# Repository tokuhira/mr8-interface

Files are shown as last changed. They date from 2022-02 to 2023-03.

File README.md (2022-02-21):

# mr8-interface

KO PROPO製のプロポセットMC-8/MR-8にマルチプレクサ機能等を追加するプロジェクトです。

# Features

CMOSロジックICのマルチプレクサを利用してプロポからの操作と別系統からの操作を選択できます。
操作系統の切り替えはMC-8の操作スティック押下で行います。
CH-Eを押すと別系統の操作が有効になり、CH-Fを押すとプロポによる手動操作に戻ります。
別系統との電気信号は絶縁されているため、異なる電源系統のユニットとも接続できます。
おまけ機能で両系統のステアリングともにリバース信号も出力します。
おまけ機能でプロポ操作に対応するS.BUS信号も出力する予定ですが、プログラムは未実装です。

# Requirement

Adafruit QT Pyが別途必要です。

# Installation

このボードとAdafruit QT Pyは直接ハンダ付けします。
このボードとMR-8の接続については回路図を参照のうえ、ハーネスもしくは添付のミニ基板を使用してください。
このボードとRCシステム（スロットルに対応するESC、ならびにステアリングに対応するサーボ）の接続についても回路図を参照してください。
TAKACHI製のプラスチックケースTW4-2-5に格納することができます。
TAKACHI製のプラスチックケースSW-40にも格納することができますが、その場合はマウントホールのはみ出し部を切り落とす必要があります。

# Usage

各々方でご自由に応用していただけます。

# Note

可用性、安全性、その他いかなる性質も保証しません。
いかなる用法も、またのその結果も保証しません。

# Author

* @tokuhira (twitter)
* github.com/tokuhira

# License

BSD 3-Clause License

Copyright (c) 2020, tokuhira.net
All rights reserved.

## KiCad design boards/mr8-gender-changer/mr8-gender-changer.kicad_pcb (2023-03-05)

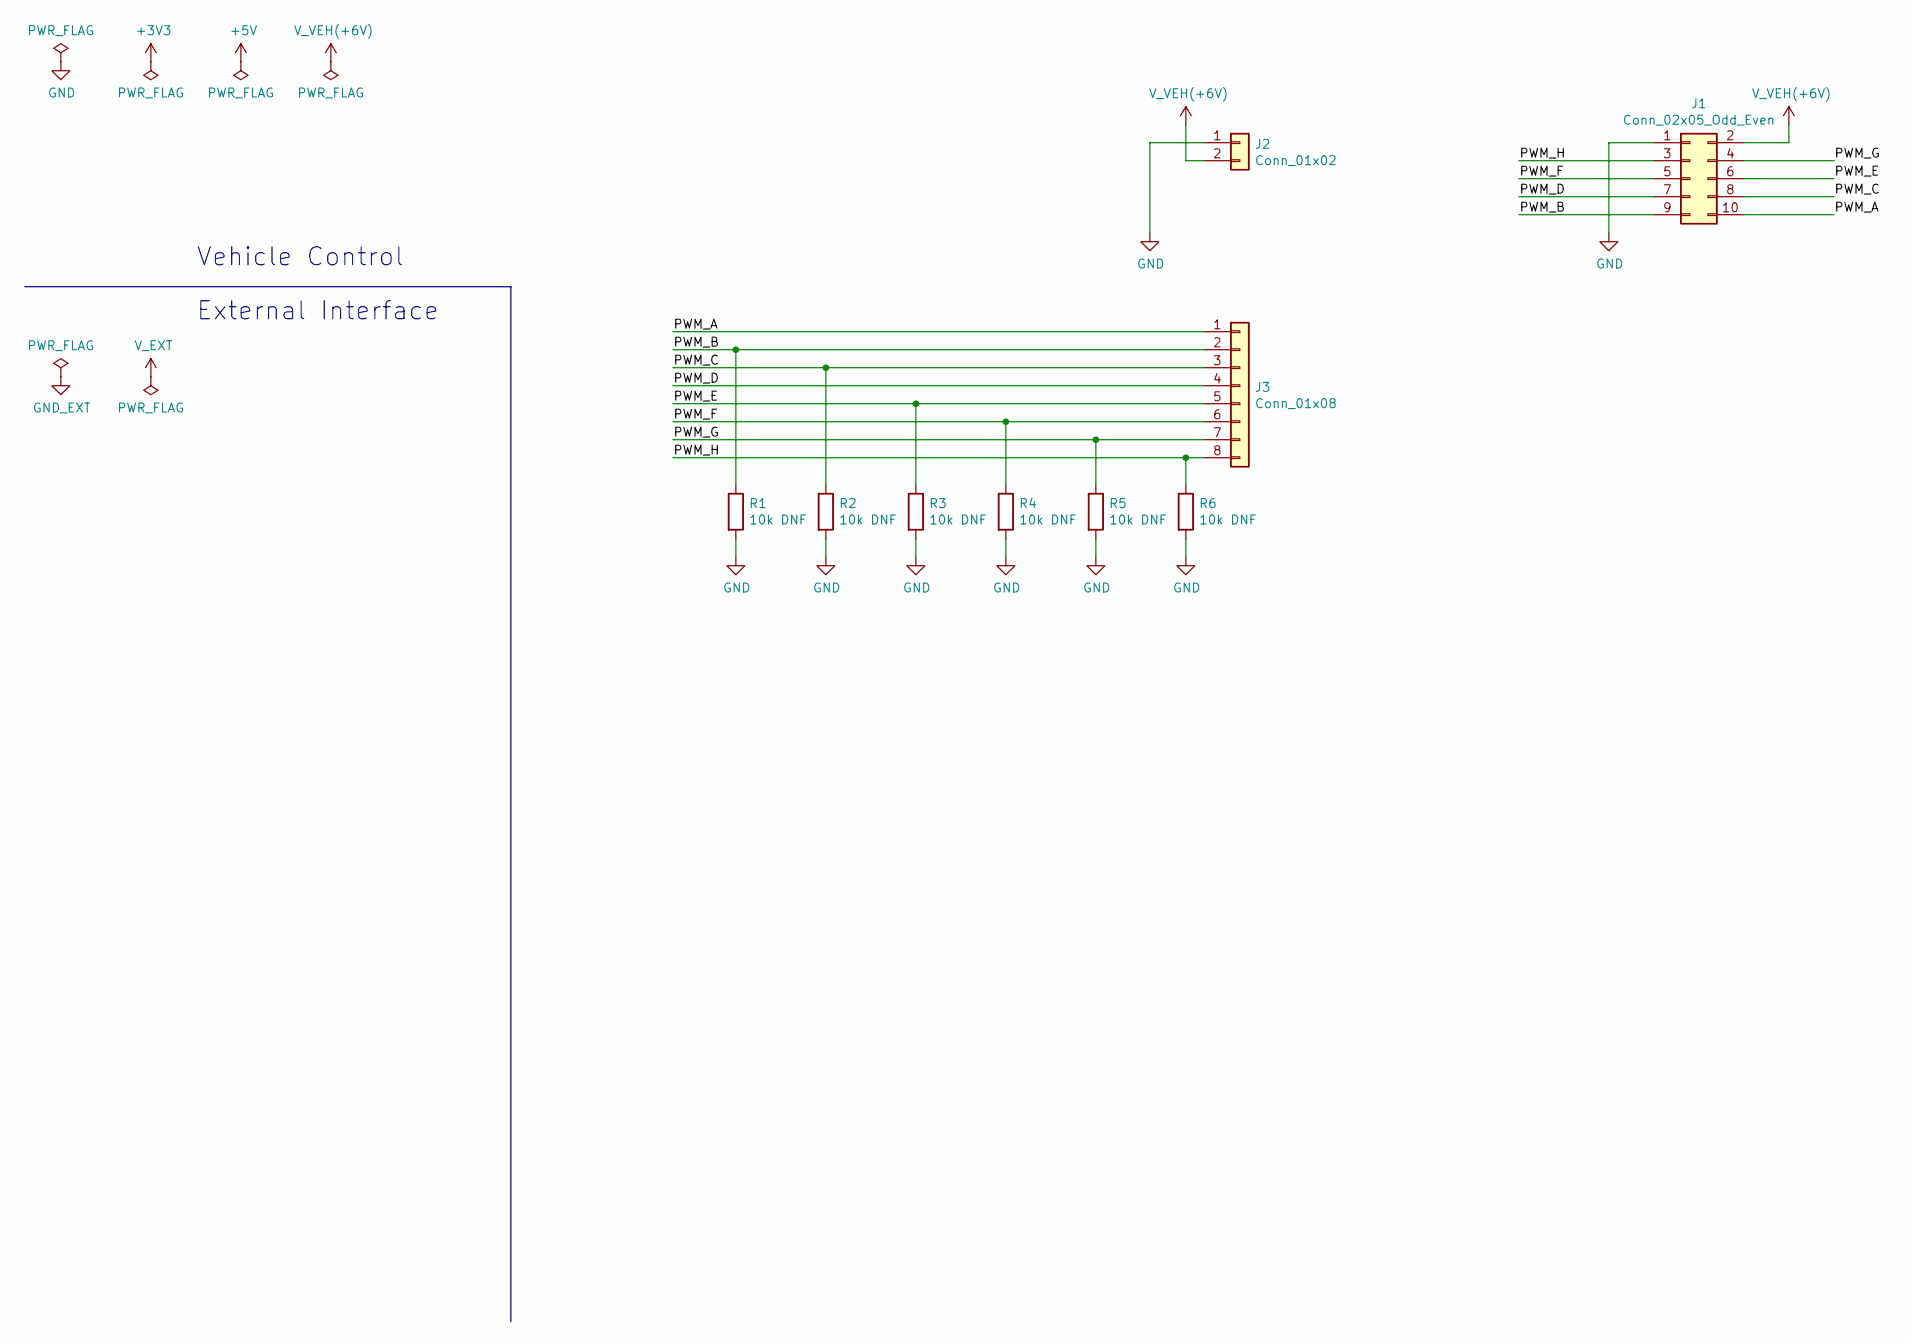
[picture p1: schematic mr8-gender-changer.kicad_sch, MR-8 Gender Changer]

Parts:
J1: Conn_02x05_Odd_Even; PinSocket_1x10_P2.54mm_Vertical
J2: Conn_01x02; PinSocket_1x02_P2.54mm_Vertical
J3: Conn_01x08; PinSocket_1x08_P2.54mm_Vertical
R1, R2, R3, R4, R5, R6: 10k DNF; R_0603_1608Metric_Pad0.98x0.95mm_HandSolder

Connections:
+V_VEH: J1.2, J2.2
/PWM_A: J1.10, J3.1
/PWM_B: J1.9, J3.2, R1.1
/PWM_C: J1.8, J3.3, R2.1
/PWM_D: J1.7, J3.4
/PWM_E: J1.6, J3.5, R3.1
/PWM_F: J1.5, J3.6, R4.1
/PWM_G: J1.4, J3.7, R5.1
/PWM_H: J1.3, J3.8, R6.1
GND: J1.1, J2.1, R1.2, R2.2, R3.2, R4.2, R5.2, R6.2

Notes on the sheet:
Vehicle Control
External Interface

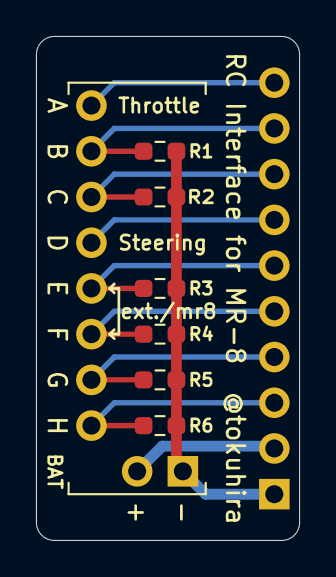
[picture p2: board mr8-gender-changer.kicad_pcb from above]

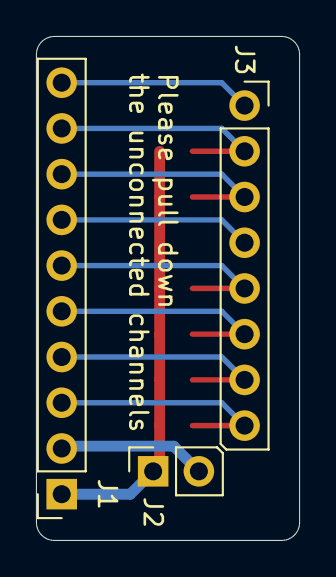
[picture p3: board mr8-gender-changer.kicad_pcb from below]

Board: 2 copper layers, 14.6 x 28.0 mm, 9 parts (3 on the bottom side), 10 nets.

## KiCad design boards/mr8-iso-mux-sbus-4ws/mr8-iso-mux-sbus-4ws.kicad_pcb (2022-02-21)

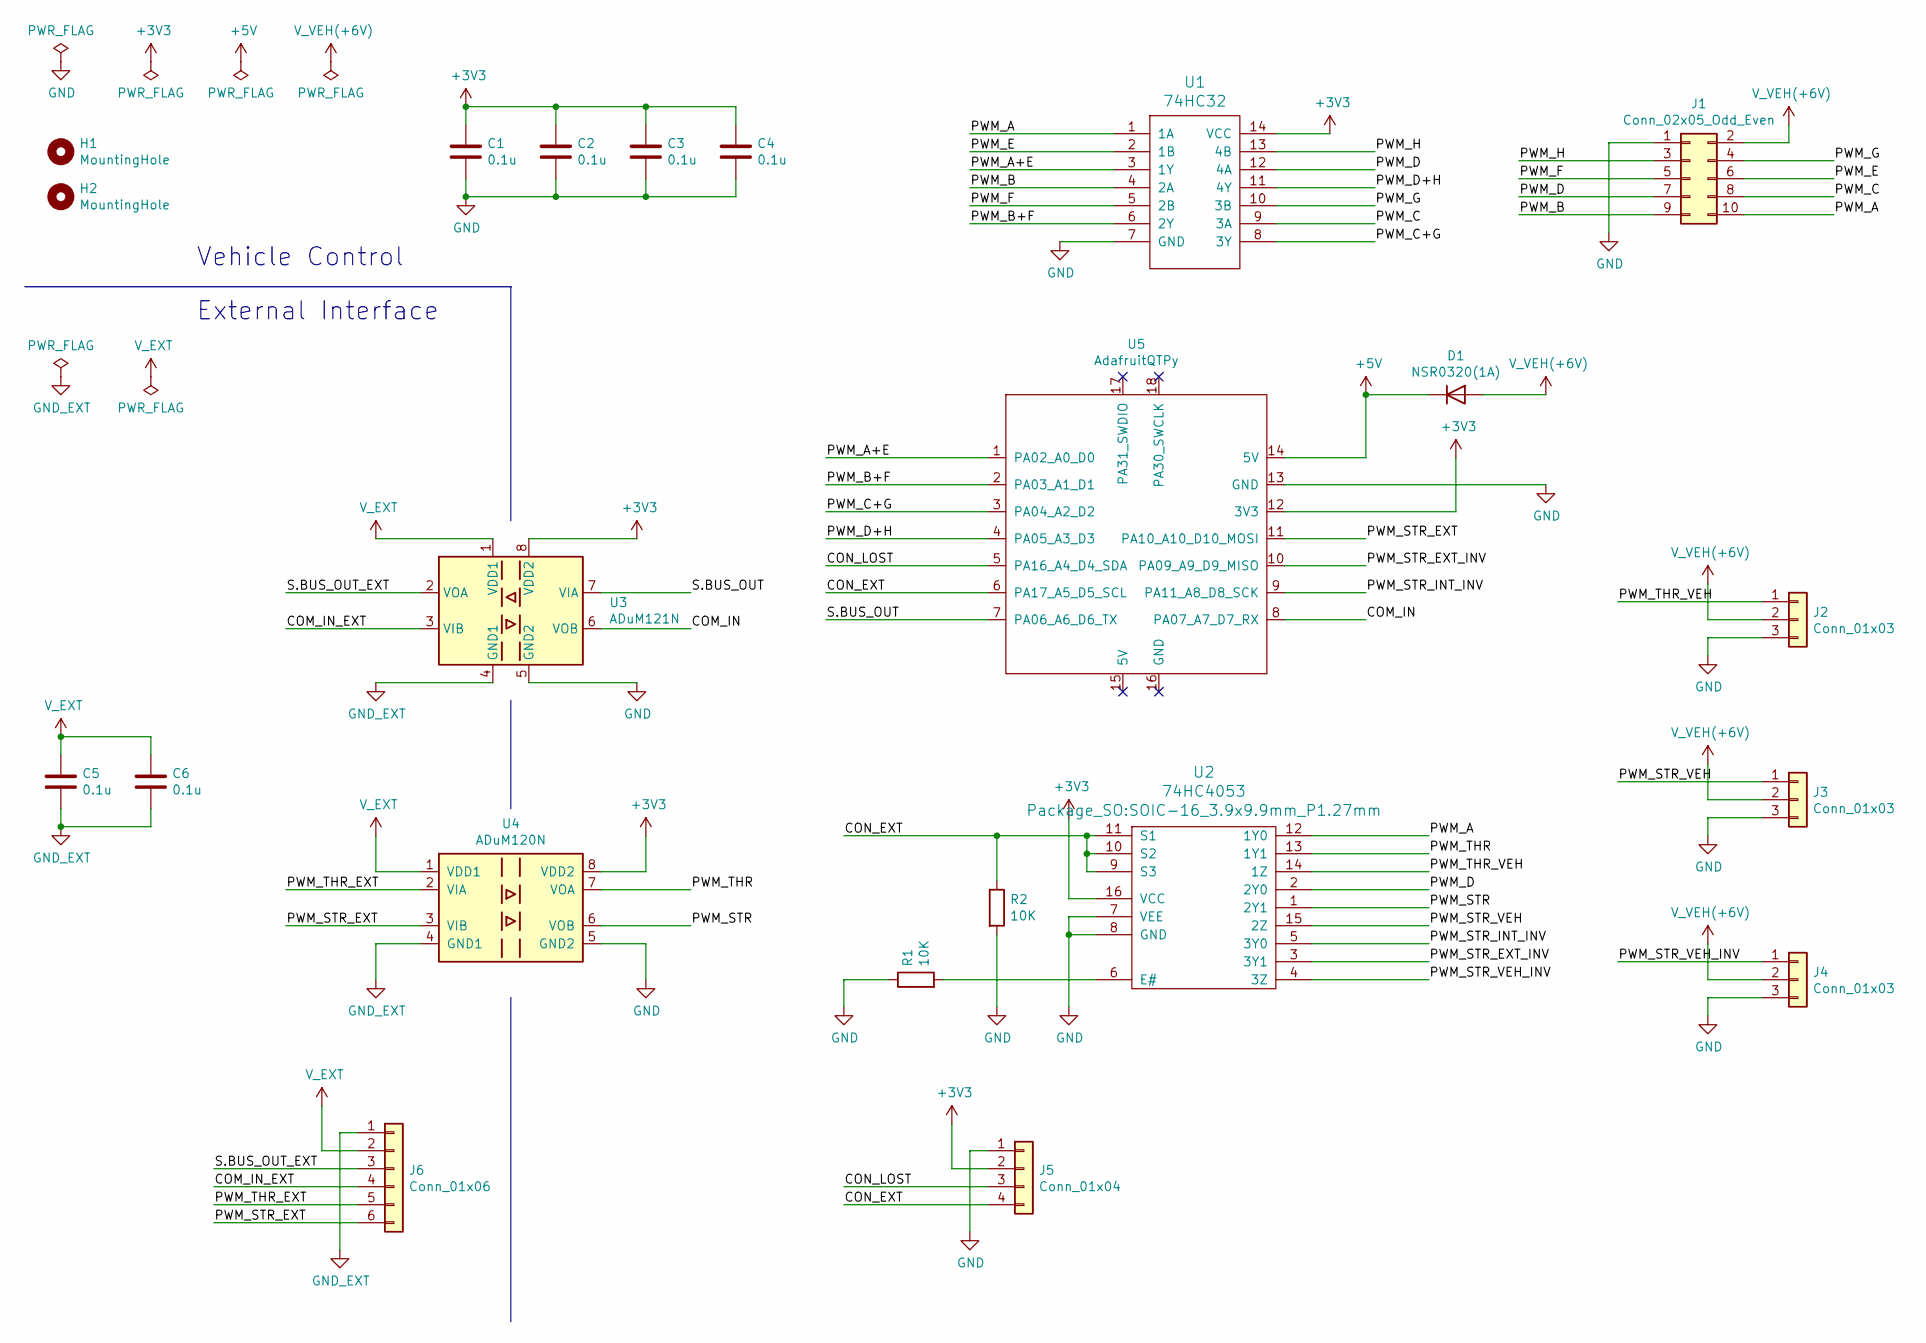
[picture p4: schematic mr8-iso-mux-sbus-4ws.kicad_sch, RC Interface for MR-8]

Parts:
C1, C2, C3, C4, C5, C6: 0.1u; C_0603_1608Metric_Pad1.08x0.95mm_HandSolder
D1: NSR0320(1A); D_SOD-323_HandSoldering
H1, H2: MountingHole; MountingHole_2.2mm_M2
J1: Conn_02x05_Odd_Even; PinHeader_1x10_P2.54mm_Vertical
J2, J3, J4: Conn_01x03; PinHeader_1x03_P2.54mm_Vertical
J5: Conn_01x04; PinHeader_1x04_P2.54mm_Vertical
J6: Conn_01x06; PinHeader_1x06_P2.54mm_Vertical
R1, R2: 10K; R_0603_1608Metric_Pad0.98x0.95mm_HandSolder
U1: 74HC32; SOIC-14_3.9x8.7mm_P1.27mm
U2: 74HC4053; SOIC-16_3.9x9.9mm_P1.27mm
U3: ADuM121N; SOIC-8_3.9x4.9mm_P1.27mm
U4: ADuM120N; SOIC-8_3.9x4.9mm_P1.27mm
U5: AdafruitQTPy; AdafruitQTPy-MOUDLE14P-2.54-21X17.8MM

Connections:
+3V3: C1.1, C2.1, C3.1, C4.1, J5.2, U1.14 (VCC), U2.16 (VCC), U3.8 (VDD2), U4.8 (VDD2), U5.12 (3V3)
+5V: D1.1 (K), U5.14 (5V)
+V_EXT: C5.1, C6.1, J6.2, U3.1 (VDD1), U4.1 (VDD1)
+V_VEH: D1.2 (A), J1.2, J2.2, J3.2, J4.2
/COM_IN: U3.6 (VOB), U5.8 (PA07_A7_D7_RX)
/COM_IN_EXT: J6.4, U3.3 (VIB)
/CON_EXT: J5.4, R2.1, U2.9 (S3), U2.10 (S2), U2.11 (S1), U5.6 (PA17_A5_D5_SCL)
/CON_LOST: J5.3, U5.5 (PA16_A4_D4_SDA)
/PWM_A: J1.10, U1.1 (1A), U2.12 (1Y0)
/PWM_A+E: U1.3 (1Y), U5.1 (PA02_A0_D0)
/PWM_B: J1.9, U1.4 (2A)
/PWM_B+F: U1.6 (2Y), U5.2 (PA03_A1_D1)
/PWM_C: J1.8, U1.9 (3A)
/PWM_C+G: U1.8 (3Y), U5.3 (PA04_A2_D2)
/PWM_D: J1.7, U1.12 (4A), U2.2 (2Y0)
/PWM_D+H: U1.11 (4Y), U5.4 (PA05_A3_D3)
/PWM_E: J1.6, U1.2 (1B)
/PWM_F: J1.5, U1.5 (2B)
/PWM_G: J1.4, U1.10 (3B)
/PWM_H: J1.3, U1.13 (4B)
/PWM_STR: U2.1 (2Y1), U4.6 (VOB)
/PWM_STR_EXT: J6.6, U4.3 (VIB), U5.11 (PA10_A10_D10_MOSI)
/PWM_STR_EXT_INV: U2.3 (3Y1), U5.10 (PA09_A9_D9_MISO)
/PWM_STR_INT_INV: U2.5 (3Y0), U5.9 (PA11_A8_D8_SCK)
/PWM_STR_VEH: J3.1, U2.15 (2Z)
/PWM_STR_VEH_INV: J4.1, U2.4 (3Z)
/PWM_THR: U2.13 (1Y1), U4.7 (VOA)
/PWM_THR_EXT: J6.5, U4.2 (VIA)
/PWM_THR_VEH: J2.1, U2.14 (1Z)
/S.BUS_OUT: U3.7 (VIA), U5.7 (PA06_A6_D6_TX)
/S.BUS_OUT_EXT: J6.3, U3.2 (VOA)
GND: C1.2, C2.2, C3.2, C4.2, J1.1, J2.3, J3.3, J4.3, J5.1, R1.1, R2.2, U1.7 (GND), U2.7 (VEE), U2.8 (GND), U3.5 (GND2), U4.5 (GND2), U5.13 (GND)
GND_EXT: C5.2, C6.2, J6.1, U3.4 (GND1), U4.4 (GND1)
unnamed: R1.2, U2.6 (E#)

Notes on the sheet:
Vehicle Control
External Interface

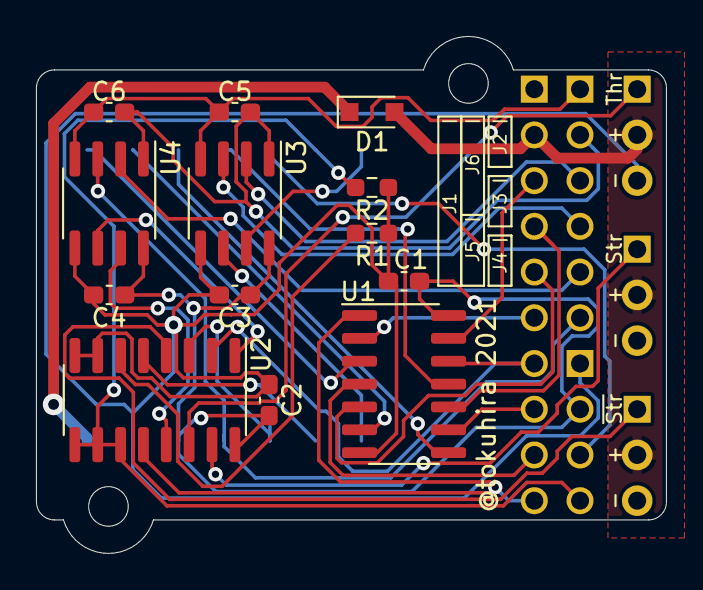
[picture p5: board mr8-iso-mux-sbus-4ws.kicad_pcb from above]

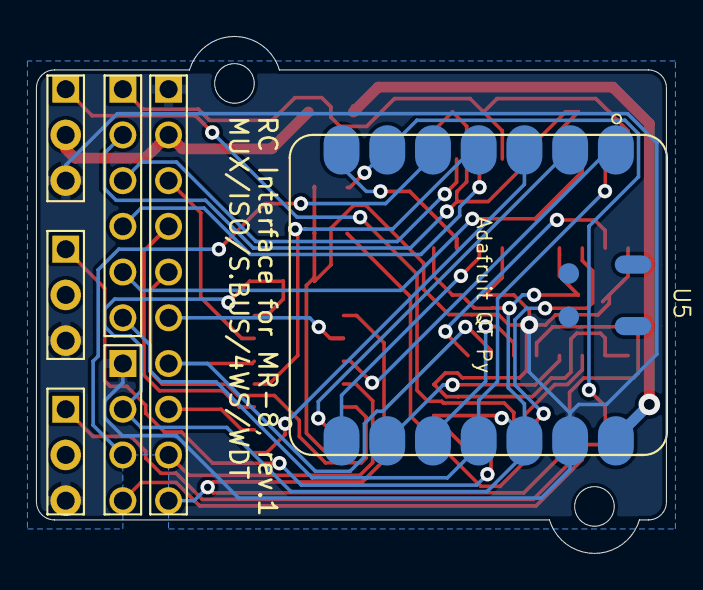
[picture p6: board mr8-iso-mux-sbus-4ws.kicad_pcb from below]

Board: 2 copper layers, 35.0 x 28.7 mm, 22 parts (7 on the bottom side), 34 nets.

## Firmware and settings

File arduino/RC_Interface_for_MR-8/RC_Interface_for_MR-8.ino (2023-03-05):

//
//  @file RC_Interface_for_MR-8.ino
//  @brief RC Interface for MR-8 (MUX/S.BUS/4WS)
//  @author tokuhira
//  @date 2021/09/29

//  QT Py     Device         　
//   0 (A0)   <=  MR8(A/E ch) via 74HC32
//   1 (A1)   <=  MR8(B/F ch) via 74HC32
//   2 (A2)   <=  MR8(C/G ch) via 74HC32
//   3 (A3)   <=  MR8(D/H ch) via 74HC32
//   4 (SDA)  =>  Controll Lost (Link down flag)
//   5 (SCL)  =>  Controll External to 74HC4053 (Pull-down)
//   6 (TX)   =>  S.BUS to host (Serial1 at QT Py)
//   7 (RX)   <=  Command from host (Serial1 at QT Py)
//   8 (SCK)  =>  MR8 D ch Steering PWM Reversed for 4WS
//   9 (MISO) =>  External Steering PWM Reversed for 4WS
//  10 (MOSI) <=  External Steering PWM from host

#include <Servo.h>
#include <Streaming.h>
#include <FUTABA_SBUS.h> // https://github.com/mikeshub/FUTABA_SBUS

Servo ExStrRev;
Servo MrStrRev;

FUTABA_SBUS sBus;

const int KO_PWM_CENTER = 1496;
const int KO_PWM_MIN = 890;
const int KO_PWM_MAX = 2100;

const int JR_PWM_CENTER = 1500;
const int JR_PWM_MIN = 900;
const int JR_PWM_MAX = 2100;

const int FUTABA_PWM_CENTER = 1520;
const int FUTABA_PWM_MIN = 1020;
const int FUTABA_PWM_MAX = 2020;

const unsigned long LINK_LIMIT0 = 15000 * 30; // waiting 0.45 sec as 30 cycles at 15 msec period (66.6 Hz)
const unsigned long LINK_LIMIT1 = 15000 * 20; // waiting 0.30 sec as 20 cycles at 15 msec period (66.6 Hz)
const unsigned long SHIFT_LIMIT = 2100 + 900; // threshold between A-D and E-H
const unsigned long PRESS_LIMIT = 1745; // neutral = 1496, pressed = 1995
const unsigned long WIDTH_MINIMUM = 900 - 100; // minimum width: 890 usec. with margin
const unsigned long WIDTH_MAXIMUM = 2100 + 100; // maximum width: 2100 usec. with margin

// const int DEBOUNCE_WAIT_COUNT = 3; // pressing E and/or F are valid when they hosd the cycles

const int MR8_AE_PIN = 0;
const int MR8_BF_PIN = 1;
const int MR8_CG_PIN = 2;
const int MR8_DH_PIN = 3;

const int CON_LST_PIN = 4;
const int CON_EXT_PIN = 5;

const int EX_STR_PIN = 10;
const int EX_STR_REV_PIN = 9;
const int MR_STR_REV_PIN = 8;

volatile unsigned long startPulse; // dual use for ABCD and EFGH
volatile unsigned long startPulseEx; // for external steering

volatile int *getPulseAE; // switching getPulse[0] or [4]
volatile int *getPulseBF; // switching getPulse[1] or [5]
volatile int *getPulseCG; // switching getPulse[2] or [6]
volatile int *getPulseDH; // switching getPulse[3] or [7]

volatile int getPulse[9]; // A/B/C/D/E/F/G/H/ExStr
volatile int outPulse[2]; // ReverseD/ReverseExStr

volatile unsigned long debounceCount[2];

volatile int mc8Link;
volatile int extMode;

inline bool isValidWidth(unsigned long pulse)
{
  return WIDTH_MINIMUM <= pulse && pulse <= WIDTH_MAXIMUM;
}

void chAEChangeInterupt()
{
  unsigned long nowPulse = micros();
  unsigned long elapsed = nowPulse - startPulse;
  if (digitalRead(MR8_AE_PIN) == HIGH)
  {
    startPulse = nowPulse; // rising event is shared by ch A/B/C/D and E/F/G/H
    if (elapsed >= SHIFT_LIMIT)
    {
      mc8Link = elapsed <= LINK_LIMIT0; // MR-8 2.4 GHz wireless link has been lost
      extMode = elapsed <= LINK_LIMIT1 ? extMode : false; // the link is going to lost
      getPulseAE = getPulse;
      getPulseBF = getPulse + 1;
      getPulseCG = getPulse + 2;
      getPulseDH = getPulse + 3;
    }
    else
    {
      getPulseAE = getPulse + 4;
      getPulseBF = getPulse + 5;
      getPulseCG = getPulse + 6;
      getPulseDH = getPulse + 7;
    }
  }
  else if (isValidWidth(elapsed))
  {
    *getPulseAE = elapsed;
  }
}

void chBFFallingInterupt()
{
  unsigned long nowPulse = micros();
  unsigned long elapsed = nowPulse - startPulse;
  if (isValidWidth(elapsed))
  {
    *getPulseBF = elapsed;
  }
}

void chCGFallingInterupt()
{
  unsigned long nowPulse = micros();
  unsigned long elapsed = nowPulse - startPulse;
  if (isValidWidth(elapsed))
  {
    *getPulseCG = elapsed;
  }
}

void chDHFallingInterupt()
{
  unsigned long nowPulse = micros();
  unsigned long elapsed = nowPulse - startPulse;
  if (isValidWidth(elapsed))
  {
    *getPulseDH = elapsed;
  }
}

void chExStrChangeInterupt()
{
  unsigned long nowPulse = micros();
  if (digitalRead(EX_STR_PIN) == HIGH)
  {
    startPulseEx = nowPulse;
  }
  else
  {
    unsigned long elapsed = nowPulse - startPulseEx;
    if (isValidWidth(elapsed))
    {
      getPulse[8] = elapsed;
    }
  }
}

int mapSteeringReverseKO(int pulse)
{
  if (pulse < KO_PWM_MIN || pulse > KO_PWM_MAX)
  {
    return KO_PWM_CENTER;
  }
  return map(pulse, KO_PWM_MIN, KO_PWM_MAX, KO_PWM_MAX, KO_PWM_MIN);
}

int mapSteeringReverseJR(int pulse)
{
  if (pulse < JR_PWM_MIN || pulse > JR_PWM_MAX)
  {
    return JR_PWM_CENTER;
  }
  return map(pulse, JR_PWM_MIN, JR_PWM_MAX, JR_PWM_MAX, JR_PWM_MIN);
}

int mapSteeringReverseKO2JR(int pulse)
{
  if (pulse < KO_PWM_MIN || pulse > KO_PWM_MAX)
  {
    return JR_PWM_CENTER;
  }
  return map(pulse, KO_PWM_MIN, KO_PWM_MAX, JR_PWM_MAX, JR_PWM_MIN);
}

int mapSteeringReverseFUTABA(int pulse)
{
  if (pulse < FUTABA_PWM_MIN || pulse > FUTABA_PWM_MAX)
  {
    return FUTABA_PWM_CENTER;
  }
  return map(pulse, FUTABA_PWM_MIN, FUTABA_PWM_MAX, FUTABA_PWM_MAX, FUTABA_PWM_MIN);
}

int mapSteeringReverseKO2FUTABA(int pulse)
{
  if (pulse < KO_PWM_MIN || pulse > KO_PWM_MAX)
  {
    return FUTABA_PWM_CENTER;
  }
  return map(pulse, KO_PWM_MIN, KO_PWM_MAX, FUTABA_PWM_MAX, FUTABA_PWM_MIN);
}

void setup() {
  Serial.begin(115200);

  // for PWM read
  pinMode(MR8_AE_PIN, INPUT);
  pinMode(MR8_BF_PIN, INPUT);
  pinMode(MR8_CG_PIN, INPUT);
  pinMode(MR8_DH_PIN, INPUT);
  pinMode(EX_STR_PIN, INPUT);
  noInterrupts();
  attachInterrupt(digitalPinToInterrupt(MR8_AE_PIN), chAEChangeInterupt, CHANGE);
  attachInterrupt(digitalPinToInterrupt(MR8_BF_PIN), chBFFallingInterupt, FALLING);
  attachInterrupt(digitalPinToInterrupt(MR8_CG_PIN), chCGFallingInterupt, FALLING);
  attachInterrupt(digitalPinToInterrupt(MR8_DH_PIN), chDHFallingInterupt, FALLING);
  attachInterrupt(digitalPinToInterrupt(EX_STR_PIN), chExStrChangeInterupt, CHANGE);
  interrupts();

  // for PWM write
  MrStrRev.attach(MR_STR_REV_PIN);
  ExStrRev.attach(EX_STR_REV_PIN);

  // for multiplexer switch
  pinMode(CON_LST_PIN, OUTPUT);
  pinMode(CON_EXT_PIN, OUTPUT);

  // status control
  debounceCount[0] = 0;
  debounceCount[1] = 0;
  mc8Link = false;
  extMode = false;

  // for S.BUS output using Serial1
  sBus.begin();
}

void loop() {
  // switching multiplexer
  if (getPulse[5] >= PRESS_LIMIT)
  {
    extMode = false;
  }
  else if (getPulse[4] >= PRESS_LIMIT)
  {
    extMode = true;
  }
  digitalWrite(CON_LST_PIN, mc8Link ? LOW : HIGH); // 2.4 GHz link down as high
  digitalWrite(CON_EXT_PIN, extMode ? HIGH : LOW); // external mode active high

  // PWM of steering reversed
  outPulse[0] = mapSteeringReverseKO2FUTABA(getPulse[3]); // MC-8 -> MR-8 -> TSU-06
  MrStrRev.writeMicroseconds(outPulse[0]);
  outPulse[1] = mapSteeringReverseFUTABA(getPulse[8]); // JR Beat2 T/R -> TSU-06
  ExStrRev.writeMicroseconds(outPulse[1]);

  // S.BUS output
  sBus.FeedLine();
  if (sBus.toChannels == 1)
  {
    sBus.UpdateServos();
    sBus.UpdateChannels();
    sBus.toChannels = 0;
    Serial << sBus.channels[0] << "," << sBus.channels[1] << "," << sBus.channels[2] << "\r\n";
  }

#ifdef DEBUG
  // debug print makes PWM poor
  Serial.print(getPulse[0]); // PWM read:  A ch
  Serial.print(",");
  Serial.print(getPulse[1]); // PWM read:  B ch
  Serial.print(",");
  Serial.print(getPulse[2]); // PWM read:  C ch
  Serial.print(",");
  Serial.print(getPulse[3]); // PWM read:  D ch
  Serial.print(",");
  Serial.print(getPulse[4]); // PWM read:  E ch
  Serial.print(",");
  Serial.print(getPulse[5]); // PWM read:  F ch
  Serial.print(",");
  Serial.print(getPulse[6]); // PWM read:  G ch
  Serial.print(",");
  Serial.print(getPulse[7]); // PWM read:  H ch
  Serial.print(",");
  Serial.print(getPulse[8]); // PWM read:  External Steering
  Serial.print(",");
  Serial.print(outPulse[0]); // PWM write: D ch REVERSED
  Serial.print(",");
  Serial.print(outPulse[1]); // PWM write: External Steering REVERSED
  Serial.print(",");
  Serial.print(mc8Link ? 1000 : 0); // State flag: RC links ok?
  Serial.print(",");
  Serial.print(extMode ? 1000 : 0); // State flag: is external?
  Serial.println(" ");
  // delay(5); // slow loop makes PWM poor
#endif

}

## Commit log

2022-02-21 Create adruino and boards
    KiCad 5.1系の基板設計データおよびS.BUS未対応のプログラム
    [mr8-gender-changer-B_Cu.gbr, mr8-gender-changer-B_Mask.gbr, mr8-gender-changer-B_Paste.gbr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]
2023-03-05 KiCad 7
    Update file names and formats for KiCad 7.
    [mr8-gender-changer.kicad_pcb, mr8-gender-changer.kicad_sch, mr8-gender-changer.sch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]
2023-03-05 Update RC_Interface_for_MR-8.ino
    Add protection from unexpected interrupts on intialization.
